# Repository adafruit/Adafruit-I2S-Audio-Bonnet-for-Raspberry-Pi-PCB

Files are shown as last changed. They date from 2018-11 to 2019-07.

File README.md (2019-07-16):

## Adafruit I2S Audio Bonnet for Raspberry Pi - UDA1334A PCB

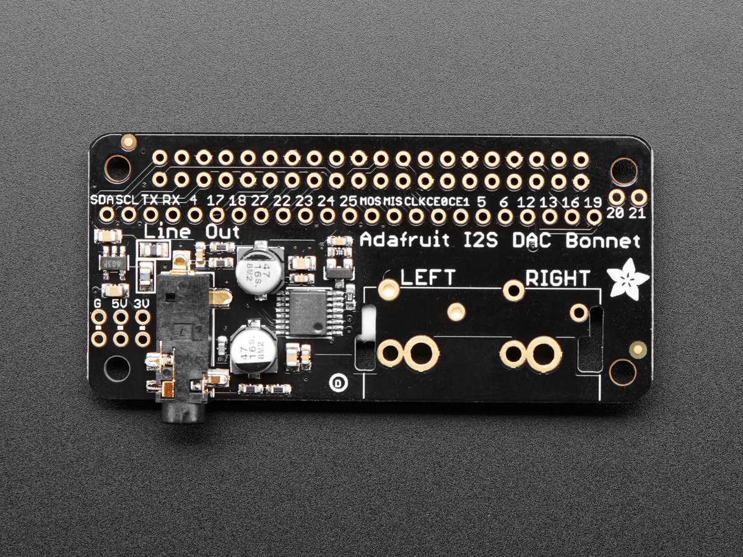
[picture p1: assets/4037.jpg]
<a href="http://www.adafruit.com/products/4037"><br/>
Click here to purchase one from the Adafruit shop</a>

PCB files for the Adafruit I2S Audio Bonnet for Raspberry Pi - UDA1334A. Format is EagleCAD schematic and board layout
* https://www.adafruit.com/product/4037

### Description

Add some easy-listenin' tunes to your Raspberry Pi using this basic audio bonnet. It'll give you stereo line out from a digital I2S converter for a good price, and sounds nice to boot! This bonnet features the UDA1334A I2S Stereo DAC, a perfect match for any I2S-output audio interface. It's affordable but sounds great - music to our ears.

It's the exact same size as a Raspberry Pi Zero but works with **any and all** Raspberry Pi computers with a 2x20 connector - A+, B+, Zero, Pi 2, Pi 3, etc. We've tested it out with Raspbian (the official operating system) and Retropie.

This Bonnet uses I2S a digital sound standard, so you get really crisp audio. The digital data goes right into the amplifier so there's no static like you hear from the onboard headphone jack. And it's super easy to get started. Just plug in any line level output into powered speakers or audio system. You can plug in headphones but you'll get some distortion - so its best used into something that is expecting line level out

Each order comes as a fully tested and assembled PCB with a 2x20 socket connector. No soldering required! [Plug it right onto your pi, install the script and reboot](https://learn.adafruit.com/adafruit-i2s-audio-bonnet-for-raspberry-pi). Pow, you're makin' lovely sounds. Want an RCA jack output? [We have a solder-in-able stereo jack as a separate component](https://www.adafruit.com/product/4171)

**Pi Zero, audio cable & speakers not included!**

### License

Adafruit invests time and resources providing this open source design, please support Adafruit and open-source hardware by purchasing products from [Adafruit](https://www.adafruit.com)!

Designed by Limor Fried/Ladyada for Adafruit Industries.

Creative Commons Attribution/Share-Alike, all text above must be included in any redistribution. See license.txt for additional details.

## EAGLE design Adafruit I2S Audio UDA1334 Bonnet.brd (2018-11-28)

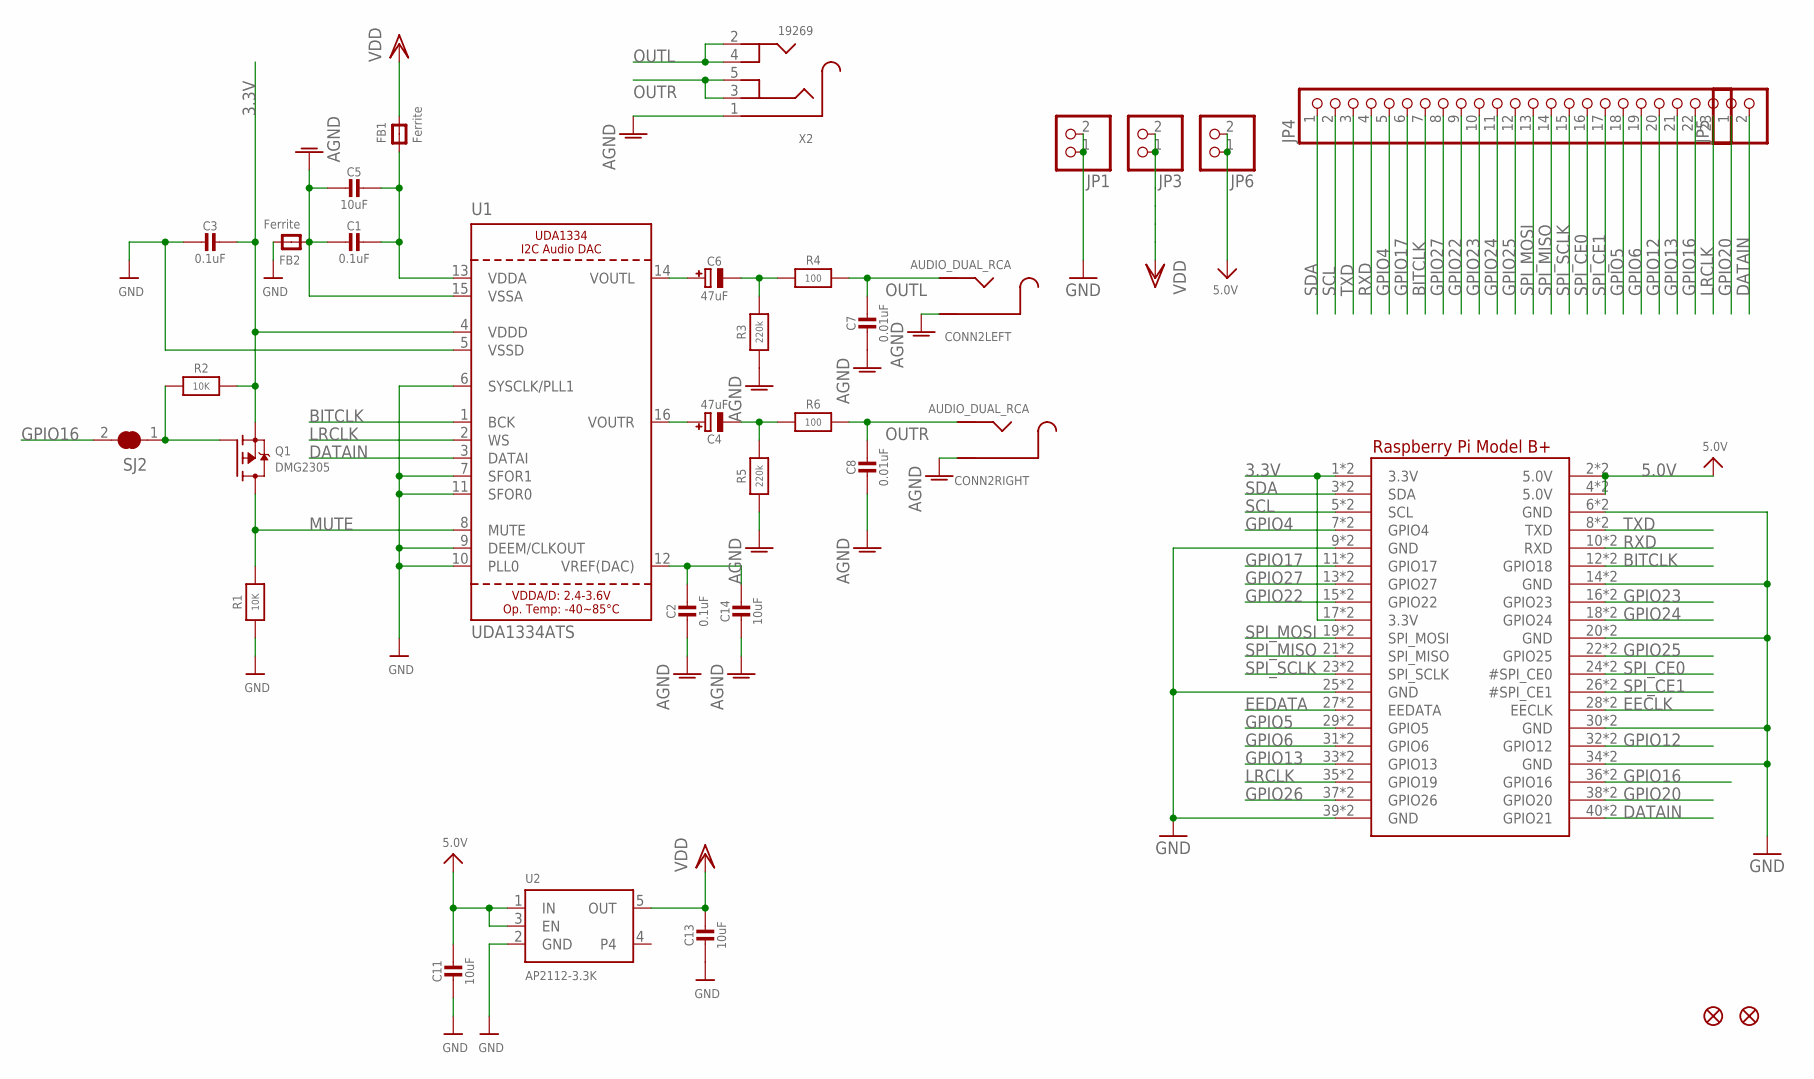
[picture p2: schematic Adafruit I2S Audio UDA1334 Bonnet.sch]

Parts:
C1, C2, C3: 0.1uF; 0603-NO
C4, C6: 47uF; PANASONIC_C
C5, C11, C13, C14: 10uF; 0805-NO
C7, C8: 0.01uF; 0603-NO
CONN2: AUDIO_DUAL_RCA; RCA_DUAL_JACK
FB1, FB2: Ferrite; 0805
FID1, FID2: FIDUCIAL_1MM
JP1, JP3, JP5, JP6: HEADER-1X2ROUND; 1X02_ROUND
JP4: HEADER-1X23; 1X23_ROUND_70MIL
Q1: DMG2305; SOT23-WIDE
R1, R2: 10K; 0603-NO
R3, R5: 220k; 0603-NO
R4, R6: 100; 0603-NO
RPI1: RASPBERRYPI_BPLUS_BONNET_THMSMT; PI_BONNET_THMSMT
SJ2: SOLDERJUMPER_CLOSED; SOLDERJUMPER_CLOSEDWIRE
U1: UDA1334ATS; SSOP16_4.4MM
U2: AP2112-3.3K; SOT23-5
X2: 19269; 4UCONN_19269

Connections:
3.3V: C3.1, Q1.2 (S), R2.2, RPI1.1 (3.3V), RPI1.17 (3.3V), RPI1.S1 (3.3V), RPI1.S17 (3.3V), U1.4 (VDDD)
5.0V: C11.1, JP6.1, JP6.2, RPI1.2 (5.0V), RPI1.4 (5.0V), RPI1.S2 (5.0V), RPI1.S4 (5.0V), U2.1 (IN), U2.3 (EN)
AGND: C1.2, C2.2, C5.2, C7.2, C8.2, C14.2, CONN2.L_G (SLEEVE), CONN2.L_G' (SLEEVE), CONN2.R_G (SLEEVE), CONN2.R_G' (SLEEVE), FB2.1, R3.1, R5.1, U1.15 (VSSA), X2.1
BITCLK: JP4.7, RPI1.12 (GPIO18), RPI1.S12 (GPIO18), U1.1 (BCK)
DATAIN: JP5.2, RPI1.40 (GPIO21), RPI1.S40 (GPIO21), U1.3 (DATAI)
EECLK: RPI1.28 (EECLK), RPI1.S28 (EECLK)
EEDATA: RPI1.27 (EEDATA), RPI1.S27 (EEDATA)
GND: C3.2, C11.2, C13.2, FB2.2, JP1.1, JP1.2, R1.1, RPI1.6 (GND), RPI1.9 (GND), RPI1.14 (GND), RPI1.20 (GND), RPI1.25 (GND), RPI1.30 (GND), RPI1.34 (GND), RPI1.39 (GND), RPI1.S6 (GND), RPI1.S9 (GND), RPI1.S14 (GND), RPI1.S20 (GND), RPI1.S25 (GND), RPI1.S30 (GND), RPI1.S34 (GND), RPI1.S39 (GND), U1.5 (VSSD), U1.6 (SYSCLK/PLL1), U1.7 (SFOR1), U1.9 (DEEM/CLKOUT), U1.10 (PLL0), U1.11 (SFOR0), U2.2 (GND)
GPIO4: JP4.5, RPI1.7 (GPIO4), RPI1.S7 (GPIO4)
GPIO5: JP4.18, RPI1.29 (GPIO5), RPI1.S29 (GPIO5)
GPIO6: JP4.19, RPI1.31 (GPIO6), RPI1.S31 (GPIO6)
GPIO12: JP4.20, RPI1.32 (GPIO12), RPI1.S32 (GPIO12)
GPIO13: JP4.21, RPI1.33 (GPIO13), RPI1.S33 (GPIO13)
GPIO16: JP4.22, RPI1.36 (GPIO16), RPI1.S36 (GPIO16), SJ2.2
GPIO17: JP4.6, RPI1.11 (GPIO17), RPI1.S11 (GPIO17)
GPIO20: JP5.1, RPI1.38 (GPIO20), RPI1.S38 (GPIO20)
GPIO22: JP4.9, RPI1.15 (GPIO22), RPI1.S15 (GPIO22)
GPIO23: JP4.10, RPI1.16 (GPIO23), RPI1.S16 (GPIO23)
GPIO24: JP4.11, RPI1.18 (GPIO24), RPI1.S18 (GPIO24)
GPIO25: JP4.12, RPI1.22 (GPIO25), RPI1.S22 (GPIO25)
GPIO26: RPI1.37 (GPIO26), RPI1.S37 (GPIO26)
GPIO27: JP4.8, RPI1.13 (GPIO27), RPI1.S13 (GPIO27)
LRCLK: JP4.23, RPI1.35 (GPIO19), RPI1.S35 (GPIO19), U1.2 (WS)
MUTE: Q1.3 (D), R1.2, U1.8 (MUTE)
unnamed: C2.1, C14.1, U1.12 (VREF(DAC))
unnamed: C1.1, C5.1, FB1.1, U1.13 (VDDA)
unnamed: C4.+, U1.16 (VOUTR)
unnamed: Q1.1 (G), R2.1, SJ2.1
unnamed: C6.+, U1.14 (VOUTL)
unnamed: C6.-, R3.2, R4.1
unnamed: C4.-, R5.2, R6.1
OUTL: C7.1, CONN2.L_SIG (TIP), CONN2.L_SIG' (TIP), R4.2, X2.2, X2.4
OUTR: C8.1, CONN2.R_SIG (TIP), CONN2.R_SIG' (TIP), R6.2, X2.3, X2.5
RXD: JP4.4, RPI1.10 (RXD), RPI1.S10 (RXD)
SCL: JP4.2, RPI1.5 (SCL), RPI1.S5 (SCL)
SDA: JP4.1, RPI1.3 (SDA), RPI1.S3 (SDA)
SPI_CE0: JP4.16, RPI1.24 (#SPI_CE0), RPI1.S24 (#SPI_CE0)
SPI_CE1: JP4.17, RPI1.26 (#SPI_CE1), RPI1.S26 (#SPI_CE1)
SPI_MISO: JP4.14, RPI1.21 (SPI_MISO), RPI1.S21 (SPI_MISO)
SPI_MOSI: JP4.13, RPI1.19 (SPI_MOSI), RPI1.S19 (SPI_MOSI)
SPI_SCLK: JP4.15, RPI1.23 (SPI_SCLK), RPI1.S23 (SPI_SCLK)
TXD: JP4.3, RPI1.8 (TXD), RPI1.S8 (TXD)
VDD: C13.1, FB1.2, JP3.1, JP3.2, U2.5 (OUT)

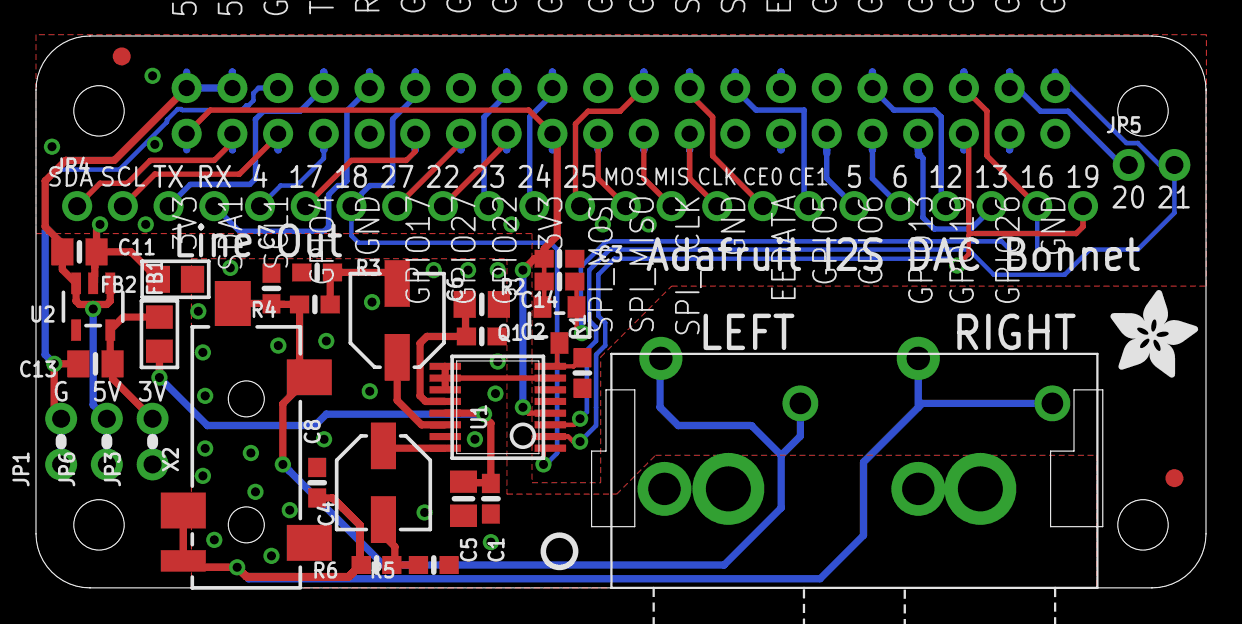
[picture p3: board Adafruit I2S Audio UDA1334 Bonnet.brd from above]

Board: 2 copper layers, 65.0 x 30.7 mm, 35 parts (1 on the bottom side), 43 nets.

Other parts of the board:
U$5: ADAFRUIT_5MM
U$11: PCBFEAT-REV-040

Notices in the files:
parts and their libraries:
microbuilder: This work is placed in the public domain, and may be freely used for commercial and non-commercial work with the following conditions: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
